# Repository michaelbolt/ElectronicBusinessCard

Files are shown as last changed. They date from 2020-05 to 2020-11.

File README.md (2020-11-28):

# ElectronicBusinessCard
This repository contains the code and PCB design files I developed for my Electronic Business Card project. To see writeups and follow my progress, follow my blog: [Mr. Dr. Prof. Bolt](https://mrdrprofbolt.wordpress.com/).

### Current State of the Project: Finished!
The MSP430FR2433 microcontroller communicates with the SSD1306 OLED display through I2C and handles 8x8 sprite-based animations. A Python GUI is available to help with creating animated sprite data. GPIO Port 2 is debounced using a polling algorithm for player input. A basic game loop implementing player controls (verical movement and lasers), enemy AI (vertical/horizontal movement and lasers), and collision detection (explosions!) is run at 16 Hz using the TimerA module and Low-Power Mode 3. Three different enemies are implemented along with collision detection and a score counter, with life-time high score stored in non-volatile FRAM. If the player gets a high score, a fireworks show is shown to celebrate!

### Using the Sprite Maker GUI
1. Download the `SpriteMaker.py` file from the `PythonScripts` folder.
2. Navigte to the directory where the source file is located. Use `cd [folder name]` to navigate on Mac/Linux or `DIR [folder name]` to navigate on Windows.
3. Run the script from the command line as `python SpriteMaker.py`. If you would like to see command line options, add the `-h` option.
4. Enjoy!

### Using the SSD1306 display functions
1. At the start of each frame, call `display_frameStart()`; this erases anything drawn on the last frame from VRAM.
2. Draw up to 16 sprites at (x,y) coordinates with `display_drawSprite(uint16_t x, uint16_t y, const uint8_t *const sprite)`.
3. After drawing all sprites, call `display_drawFrame()`; this updates all changed regions of the SSD1306 display with minimal I2C communication.

### Board Design files
Open in Eagle, edit the silkscreen to show your name, and go forth! Impress job interviewers, your friends, and anybody sitting next to you while waiting for a table at a restaurant!

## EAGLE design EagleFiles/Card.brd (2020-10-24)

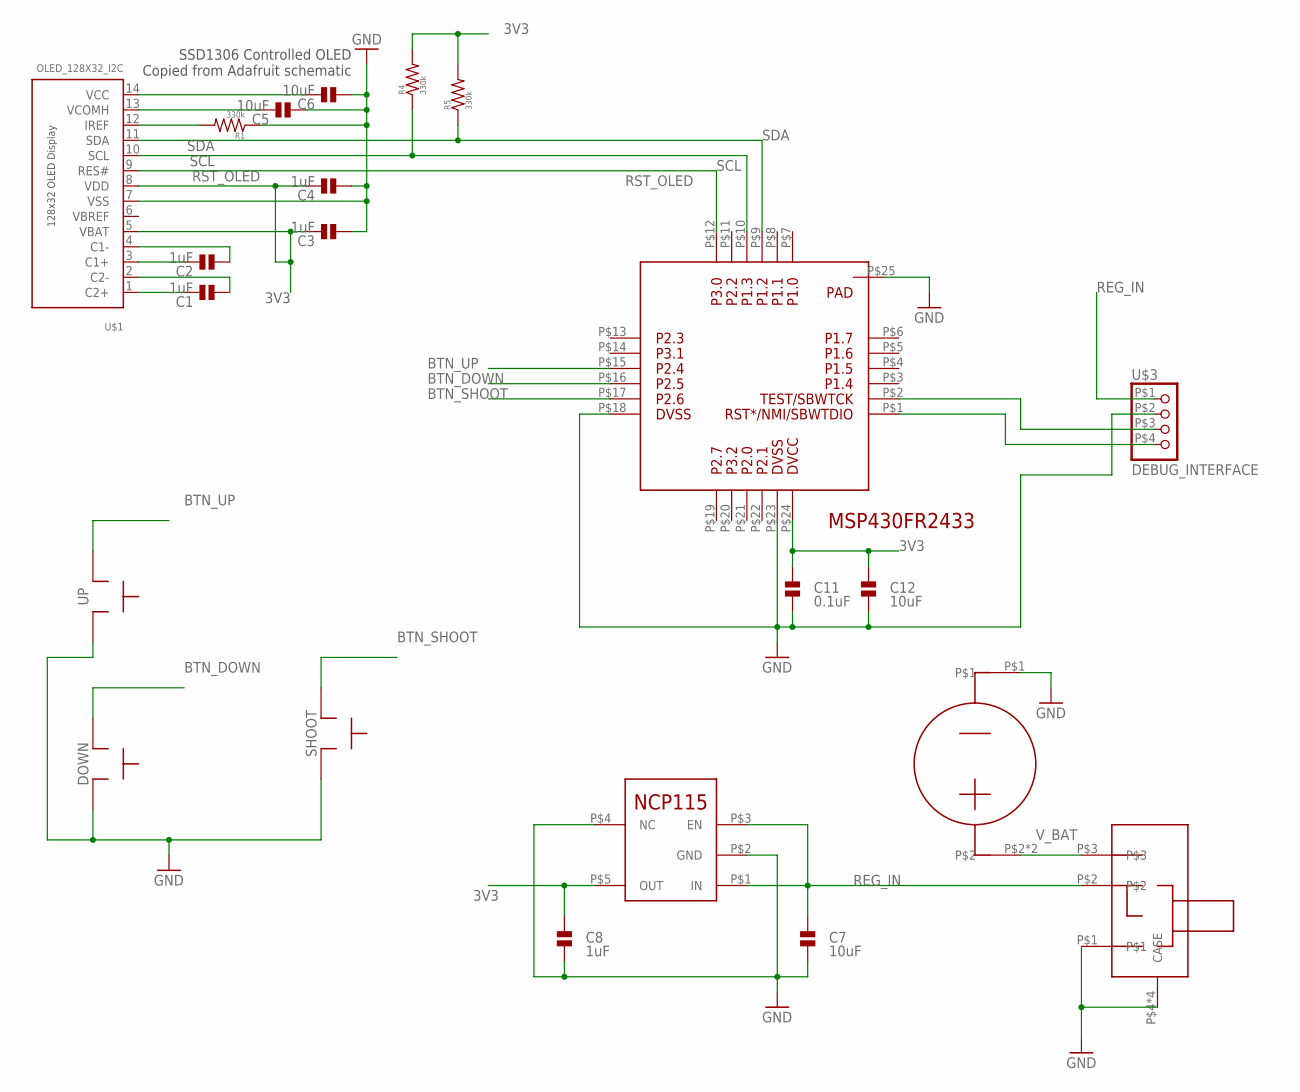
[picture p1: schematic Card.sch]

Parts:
C1, C2, C3, C4, C8: 1uF; 0603
C5, C6, C7, C12: 10uF; 0603
C11: 0.1uF; 0603
DOWN: EVQ-Q2B02W; EVQQ2
R1, R4, R5: 330k; 0603
SHOOT: EVQ-Q2B02W; EVQQ2
U$1: OLED_128X32_I2C; OLED_I2C
U$2: MSP430FR2433-VQFN; VQFN-24
U$3: DEBUG_INTERFACE; DEBUG_INTERFACE_6PIN
U$4: BAT-HLD-001
U$5: CUS-12TB; CUS-12B
U$6: NCP115; TSOP-5
UP: EVQ-Q2B02W; EVQQ2

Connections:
3V3: C3.2, C4.2, C8.2, C11.2, C12.2, R4.2, R5.2, U$1.5 (VBAT), U$1.8 (VDD), U$2.P$24, U$6.P$5 (OUT)
BTN_DOWN: DOWN.P$1_A, DOWN.P$2_A, U$2.P$16
BTN_SHOOT: SHOOT.P$1_A, SHOOT.P$2_A, U$2.P$17
BTN_UP: U$2.P$15, UP.P$1_A, UP.P$2_A
GND: C3.1, C4.1, C5.1, C6.1, C7.1, C8.1, C11.1, C12.1, DOWN.P$3_B, DOWN.P$4_B, R1.1, SHOOT.P$3_B, SHOOT.P$4_B, U$1.7 (VSS), U$2.P$18, U$2.P$23, U$2.P$25, U$3.P$2, U$4.P$1, U$5.P$1, U$5.P$4 (CASE), U$5.P$5 (CASE), U$5.P$6 (CASE), U$5.P$7 (CASE), U$6.P$2 (GND), U$6.P$4 (NC), UP.P$3_B, UP.P$4_B
unnamed: C1.2, U$1.1 (C2+)
unnamed: C1.1, U$1.2 (C2-)
unnamed: C2.2, U$1.3 (C1+)
unnamed: C2.1, U$1.4 (C1-)
unnamed: U$2.P$2, U$3.P$3
unnamed: U$2.P$1, U$3.P$4
unnamed: R1.2, U$1.12 (IREF)
unnamed: C5.2, U$1.13 (VCOMH)
unnamed: C6.2, U$1.14 (VCC)
REG_IN: C7.2, U$3.P$1, U$5.P$2, U$6.P$1 (IN), U$6.P$3 (EN)
RST_OLED: U$1.9 (RES#), U$2.P$12
SCL: R4.1, U$1.10 (SCL), U$2.P$10
SDA: R5.1, U$1.11 (SDA), U$2.P$9
VBREF: U$1.6 (VBREF)
V_BAT: U$4.P$2, U$4.P$3, U$5.P$3

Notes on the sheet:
SSD1306 Controlled OLED Copied from Adafruit schematic

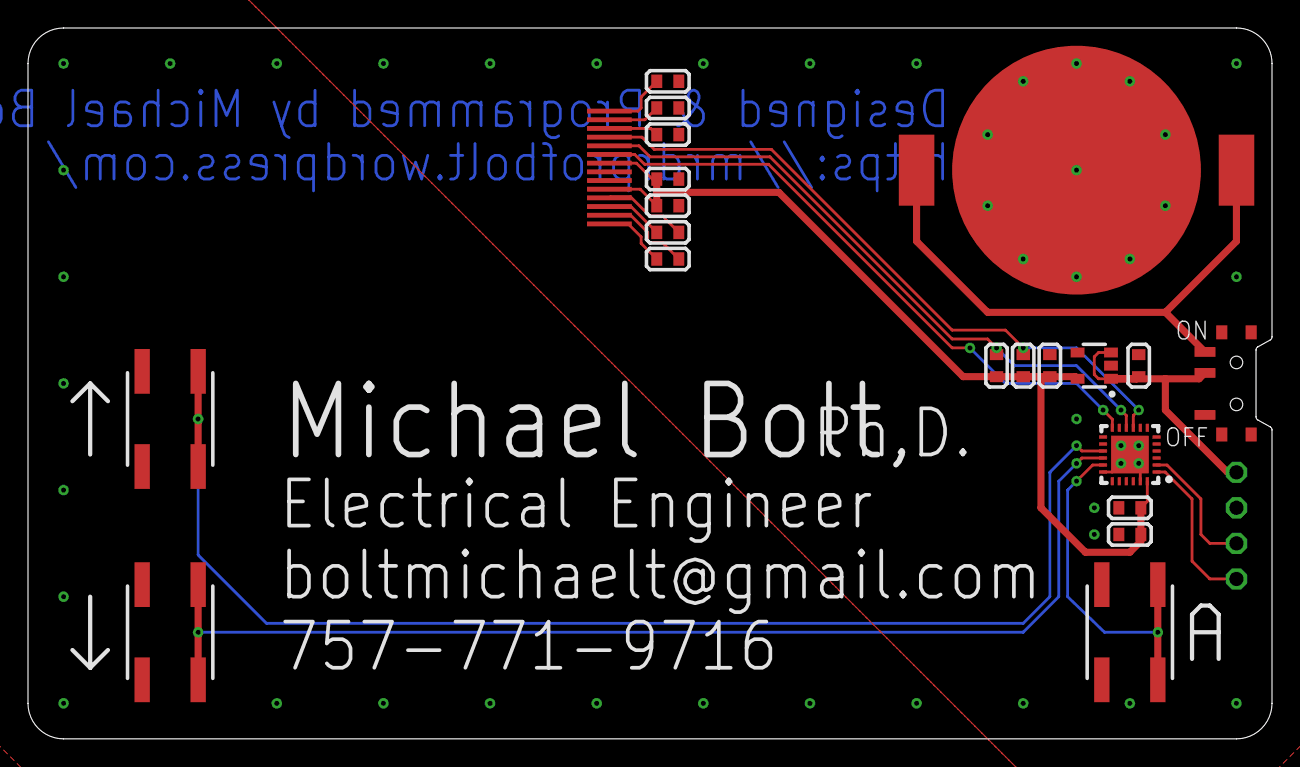
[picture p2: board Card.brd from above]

Board: 2 copper layers, 88.9 x 50.8 mm, 22 parts (0 on the bottom side), 19 nets.

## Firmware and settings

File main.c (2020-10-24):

/*
 * main.c
 *
 *  Created on: April 9, 2020
 *      Author: Michael Bolt
 */

#include <msp430.h>
#include <stdint.h>
#include "hardware.h"
#include "i2c.h"
#include "ssd1306.h"
#include "game.h"


// main
void main(void) {
    WDTCTL = WDTPW | WDTHOLD;               // Stop watchdog timer
    PM5CTL0 &= ~LOCKLPM5;                   // Disable the GPIO power-on default high-impedance mode
                                            // to activate previously configured port settings

    clockSytem_init();  // set MCLK and SMCLK to 16 MHz
    timer_init();       // initialize 16 Hz timer for constant frame rate
    buttons_init();     // configure pushbuttons and debouncing routine
    i2c_init();         // initialize I2C interface
    ssd1306_init();     // initialize SSD1306 OLED

    // enable interrupts
    __bis_SR_register(GIE);

    // clear screen
    display_clearScreen();
    // infinite main loop
    while(1) {
        // initialize game
        unsigned int frameCount = 0;
        gameInit(NEW_GAME);
        // game loop until the player runs out of lives
        unsigned int num_lives = 3;
        unsigned int enemy_spawn_counter = ENEMY_SPAWN_RATE_MIN;
        while(num_lives) {
            // randomly spawn enemies
            enemy_spawn_counter--;
            if (!enemy_spawn_counter) {
                uint16_t enemy_type = randomNumber() & 0x03;
                uint16_t y_position = randomNumber() % ENEMY_Y_MAX;
                addEnemy(enemy_type, y_position);
                enemy_spawn_counter = randomNumber() &0x0F;
                if (enemy_spawn_counter < ENEMY_SPAWN_RATE_MIN)
                    enemy_spawn_counter = ENEMY_SPAWN_RATE_MIN;
            }
            // start frame
            display_frameStart();

            playerController();                 // 1. update player character with user input
            updateEnemies();                    // 2. update enemy positions and actions
            updateLasers();                     // 3. update player and enemy laser positions
            checkCollisions();                  // 4. check if anybody needs to blow up,
                                                //    update lives and score counters
            drawPlayer();                       // 5. draw the player sprite (if alive)
            drawEnemies();                      // 6. draw the enemy sprites (if alive)
            drawLasers();                       // 7. draw the laser sprites (if alive)
            drawExplosions();                   // 8. draw any explosions
            drawScore(PLAYER_SCORE, 128, 27);   // 9a. draw the current player score
            drawScore(HIGH_SCORE, 74, 27);      // 9b. draw the current high score
            num_lives = drawLives();            // 10. draw the current number of lives

            // render the screen
            display_drawFrame();

            // sleep until next frame
            timer_sleep();

            frameCount++;
        }
        // when game over occurs...
        if (saveHighScore()) {                  // if a high-score did occur...
            // clear screen
            display_clearScreen();
            // clear frameCount to begin New High Score animation
            frameCount = 0;
            while (frameCount < HIGH_SCORE_ANIMATION_LENGTH) {
                // start frame
                display_frameStart();

                // add explosions
                highScoreAnimation(frameCount);     // add animations
                drawExplosions();                   // animate explosions
                drawScore(HIGH_SCORE, 74, 27);      // draw the new high score

                // render the screen
                display_drawFrame();

                // sleep until the next frame
                timer_sleep();

                // increment New High Score animation frame counter
                frameCount++;
            }
        }
        // restart the infinite main loop
    }
}

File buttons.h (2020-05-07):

/*
 * buttons.h
 *
 *  Created on: May 4, 2020
 *      Author: Michael Bolt
 */

#ifndef BUTTONS_H_
#define BUTTONS_H_


#include <msp430.h>
#include <stdint.h>

// button definitions
#define BTN_UP      BIT2
#define BTN_DOWN    BIT1
#define BTN_SHOOT   BIT0

// functions
void buttons_init(void);
inline uint16_t readButton(uint16_t button);


#endif /* BUTTONS_H_ */

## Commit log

2020-04-08 Created basic i2c initialization and transmission functions. TODO: test i2c functions with hardware
2020-05-01 Edge-triggered button ISR on P2.0 (demonstrates bouncing)
2020-05-04 Created buttons.h/c to provide button debouncing/reading.
2020-05-13 -Implemented 16 Hz timer for constant frame rate -Changed buttons.h/c to hardware.h/c
2020-05-20 Added Ace Pilot lasers
2020-10-24 Added Board files
    Added Eagle component library and Business Cared schematic/board files
    [Card.brd, Card.sch]
2020-10-24 Adding Documentation
    Added relevant datasheets and system pinout documents
    [PinPlanning.xlsx]
